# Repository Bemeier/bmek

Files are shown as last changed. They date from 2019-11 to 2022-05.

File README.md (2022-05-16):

# Hardware for BMEK - Bemeier Ergonomic Keyboard

First Alu Prototype

BMEK is an ergonomic keyboard in the spirit of [Lyn's EM7](https://geekhack.org/index.php?topic=83328.0) and [TGR Alice](https://geekhack.org/index.php?topic=95009.0).
Notable differences are the [HHKB-like](https://www.hhkeyboard.com/) layout and the and the more symmetric looks due to the space bars and left key cluster arrangement.

- [Geekhack Thread](https://geekhack.org/index.php?topic=103032.0)
- [Discord Server](https://discord.gg/BFZNmtM)
- [More Pictures 1](https://imgur.com/a/tHlaMWA)
- [More Pictures 2](https://imgur.com/a/MdbbHqe)

## Layout

The main key layout (besides the extra 4 key-cluster on the left) is almost exactly the [Layout of the HHKB](https://deskthority.net/wiki/HHKB_Professional2). The only changes are in the bottom row:

- The 1.5u modifiers are replaced by 1.25u modifiers
- The single spacebar is replaced by two smaller ones

### Layout with PCB V2 + V2.1

These versions of the PCB only support the fixed layout as described above. Note that you'll need 2x2.75 spacebars. Most GMK (spacebar) kits only come with one, but you can always use a 2.75u or 2.25 shift key or spacebar and live with a little gap :)

### Layout with PCB V3

V3 of the PCB supports a 2u backspace option, as well as 2.25u/2.75u layout options for the spacebars (the new version of the case comes with a "blocker" to fill in the gap that is created when using the 2.25u spacebar) and an option to use full or split rshift.

## Firmware

Setup QMK and run `make bemeier/bmek:default`

Alternatively you can download and flash the precompiled firmware from the [Releases](https://github.com/Bemeier/bmek/releases) section. Firmware Source: [TODO: Release](https://github.com/qmk/qmk_firmware/tree/master/keyboards/bemeier/bmek), [Dev](https://github.com/Bemeier/qmk_firmware/tree/bemeier/keyboards/bemeier/bmek)

## PCB

### V3 (latest version)

V3 Image

Version 3 of the PCB comes in either hotswap or solder version. It includes the extra cutouts for the plate screws from v2.1. It further comes with these changes compared to v2.x:

- Layout option backspace: 2u Backspace and 2x 1u hhkb-like
- Layout options bottom row: Each of the 2.75u spacebarss can be replaced with a 2.25u spacebar for better keyset compatibility.
- ESD protection circuity
- Switched to the popular, cheaper and easier to hand-solder HRO-TYPE-C-31-M-12 USB-C receptacle
- Made completely from scratch in KiCad (project will be released as soon as design is verified)

All Gerber & BOM files needed for ordering at JLCPCB are under [pcb](https://github.com/Bemeier/bmek/tree/master/pcb).
It can be ordered with pick-and-place assembly. Only top-mounted LEDs (optional), hot-swap sockets (optional) and USB-C connector need to be ordered separately and soldered by hand.

### Old PCB versions (V2 & V2.1)

With these versions, both hot-swap sockets and permanent soldering are supported. Connector is USB-C, and is confirmed to also work with USB-C to USB-C cables.

PCBv2 top
PCBv2 bottom

### Differences between PCB v2 and v2.1

PCB v2.1 adds some changes to fit the new plate-based design. Namely cutouts to access the scews that mount the plate to the top-case. Note that these are not strictly required to build the new case, but it is a bit more convenient (in case you want to swap out your plate+switch+pcb assembly without desoldering everything).

## Cases

### Top-mounted plate Case (Latest Version)

A top-mounted version of the original case is being designed under [cases/top_mount](https://github.com/Bemeier/bmek/tree/master/cases/top_mount). This is the case I would recommend building - especially if you want to 3D print parts, I'd suggest to print top and bottom case, but get the plate cut/machined from metal (as this is the part where the tolerances are most important.

Top Mounted 1
Top Mounted 2
Top Mounted 3

### Integrated Case (Old Verison)

3D models for a 2-piece high profile case with integrated plate mounts (intended for CNC-machining from polycarbonate or aluminium) are under [cases/old_integrated_plate_case](https://github.com/Bemeier/bmek/tree/master/cases/old_integrated_plate_case).

BMEK
Case Assembled

### Lasercut Case

Lasercut Case material Acrylic. made by [tahutech](https://github.com/TahuTech)

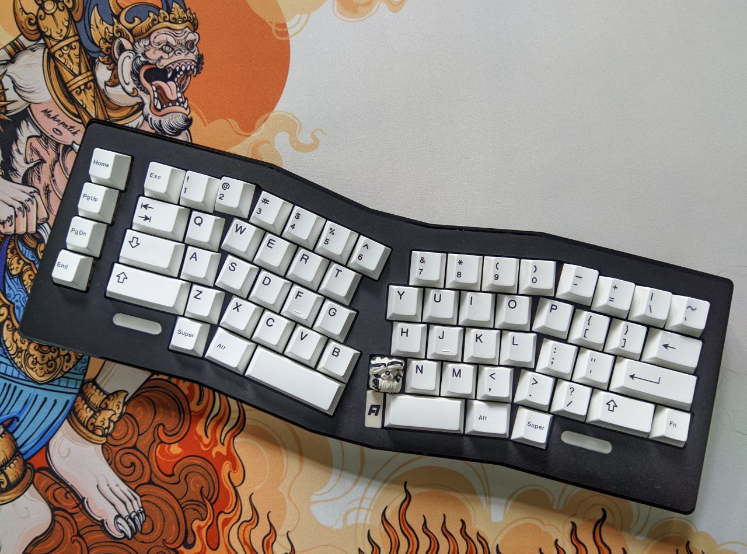
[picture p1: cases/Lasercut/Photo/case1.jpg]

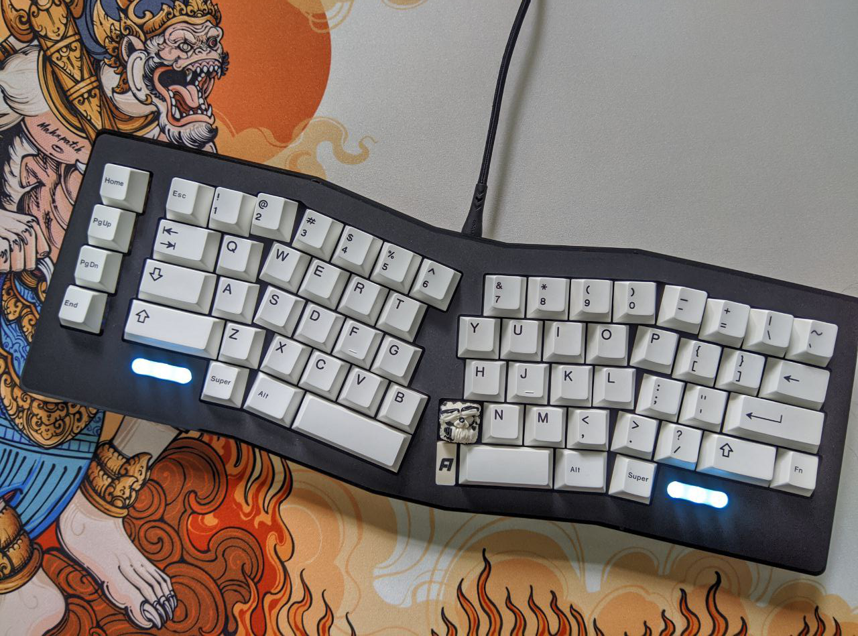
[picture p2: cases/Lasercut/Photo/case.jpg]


## Disclaimer & Contributing

Obviously you will be building the PCB or case at your own risk, but feel free to reach out if you need help or want to contribute. Check out the [geekhack thread](https://geekhack.org/index.php?topic=103032.0), [Discord Server](https://discord.gg/BFZNmtM), or use the issue system on this repository.

## License

<br /><span xmlns:dct="http://purl.org/dc/terms/" property="dct:title">BMEK Mechanical Keyboard</span> by <a xmlns:cc="http://creativecommons.org/ns#" href="http://github.com/Bemeier/bmek" property="cc:attributionName" rel="cc:attributionURL">Jan Kolkmeier</a> is licensed under a <a rel="license" href="http://creativecommons.org/licenses/by/4.0/">Creative Commons Attribution 4.0 International License</a>.

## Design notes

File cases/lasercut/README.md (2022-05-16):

# BMEK Lasercut Case

The Final result after all assemble

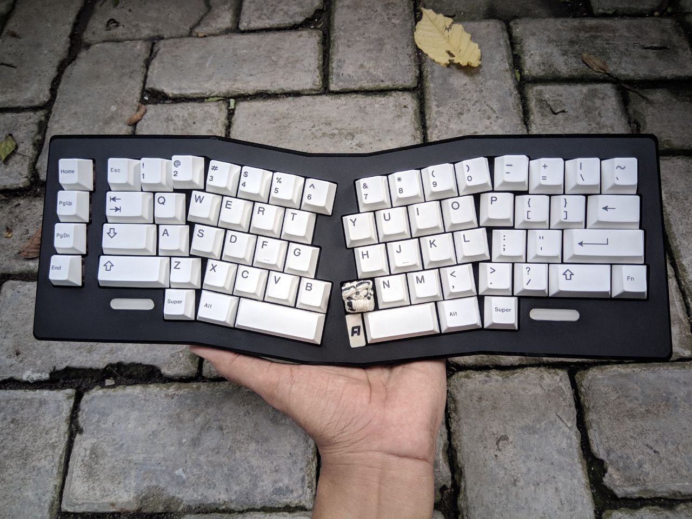
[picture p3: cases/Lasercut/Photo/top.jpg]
Top Case

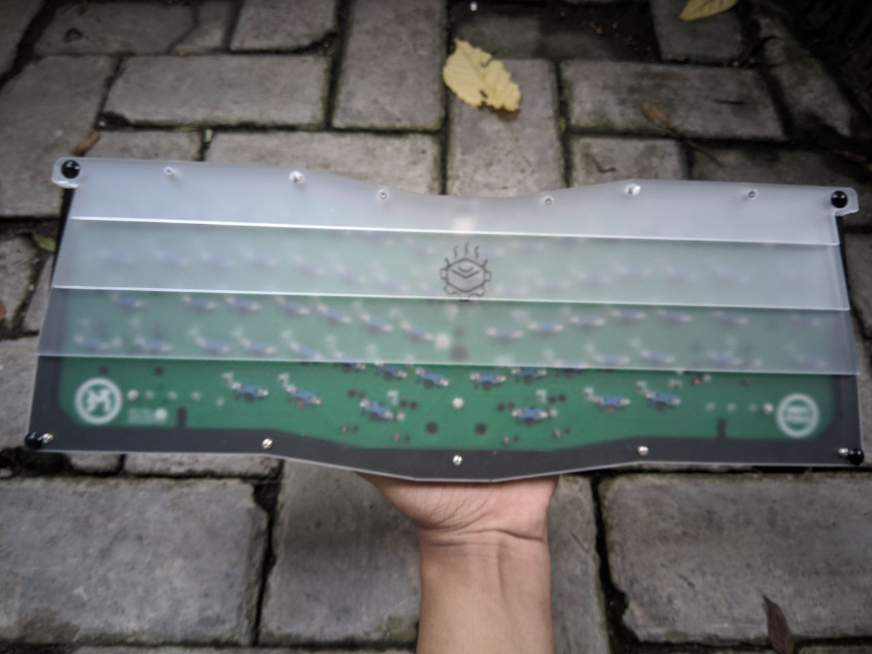
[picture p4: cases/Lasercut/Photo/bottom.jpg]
Bottom Case

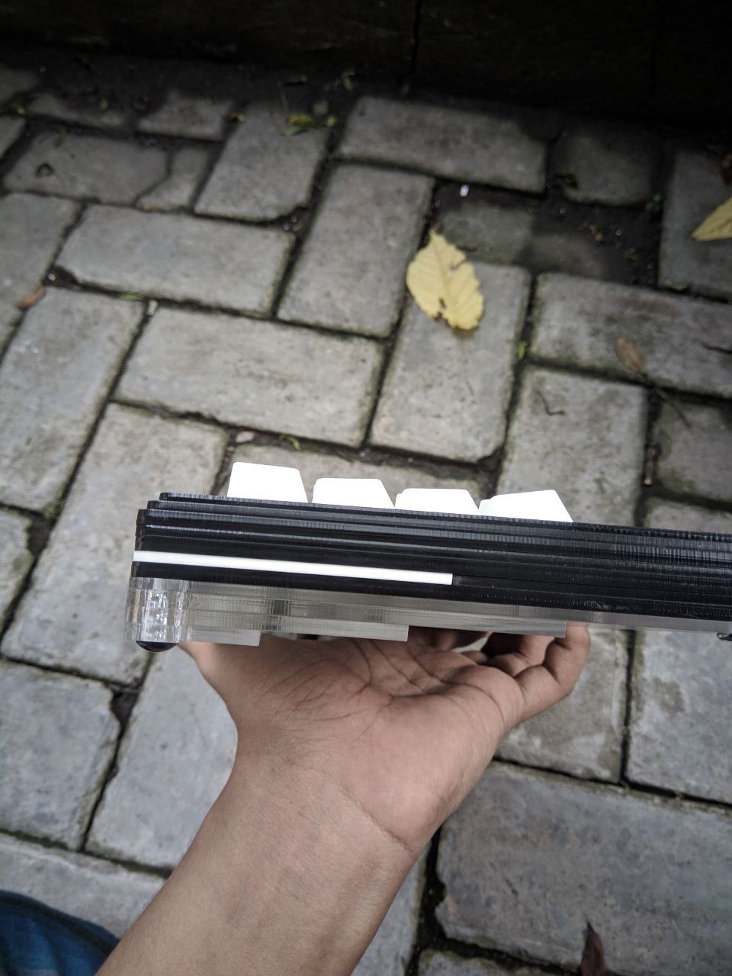
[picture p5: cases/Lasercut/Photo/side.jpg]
Side Case

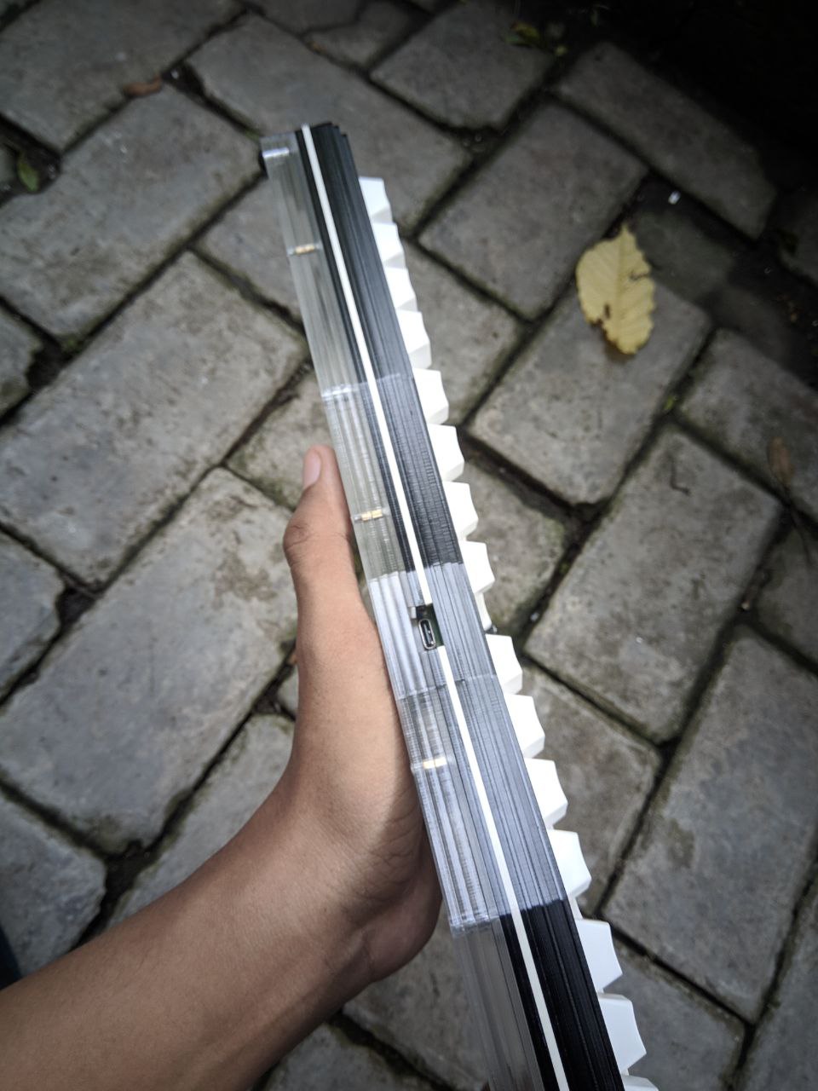
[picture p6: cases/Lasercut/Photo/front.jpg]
Front Case


[Lasercut Album](https://imgbox.com/g/qNx6dZnEyE)

# Spacer And Screws Required:

Feet to Bottom Layer:

- 4x 5mm M2 spacer and 8 screw 5mm M2 to feet (recommend countersunk head).

Top Case (Screwless):

- 9x 5mm M2 screw with countersunk head (install on second layer).
- first layer is glued to the second layer.

Body Case :

- 9x 10mm M2 spacer and 9x 6mm M2 Screw.

Tips on Accent and Blocker:

- just paste it using double tape on bottom side.

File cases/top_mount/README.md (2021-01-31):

# BMEK High-Profile Case with Plate

In each part folder there is a technical drawing, which include annotations of the screw threads.

# Build Instructions

Find some tips and build instructions in Instructions.pdf

# Screws Required:

Bottom Case to Top Case Screws:
- 5x ISO 4762 M2.5x0.45x8mm (Hex head with diameter <=4.5mm) (2.5x0.45x8mm length should also work)

Plate to Top Case Screws:
- 8x ISO 4762 M2x0.4x4mm (Hex head with diameter <= 3.8mm, head hight <= 2mm)

PCB to Top Case Screw:
- 5x ISO 4762 M2x0.4x4mm (Hex head with diameter <= 3.8mm, head hight <= 2mm)

Screw for the 2.25u layout blocker:
- 1x ISO 4762 M2x0.4x4mm

Weight to Bottom Case Screw:
- 3x ISO 10642 M3x0.5x6mm (Sinkhead, total length is <= 6mm) 

# PCB:

Compatible both with the [v3](https://github.com/Bemeier/bmek/tree/master/pcb/v3), [v2](https://github.com/Bemeier/bmek/tree/master/pcb/v2) and [v2.1](https://github.com/Bemeier/bmek/tree/master/pcb/v2_1) of the PCB (however v3/2.1 is recommended, [see this post](https://geekhack.org/index.php?topic=103032.msg2909167#msg2909167))

# Renders

Render

Technical Drawing

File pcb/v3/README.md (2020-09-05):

# V3 of the PCB

This is the PCB as it will be shipped in the group buy. It comes in both a solder and hotswap version. 
I've ordered a test batch from JLCPCB with these files and I'll update the readme here to confirm that it works as expected.
Either way, *order these files at your own risk*.
And most importantly, always critically review the parts placement (oftentimes the previewer on the JLCPCB website is broken, so ask for a review of the parts placement per mail!)

## Improvements over V2/2.1

- Separate design for hotswap and solder versions (to avoid the [potential interference issue](https://www.youtube.com/watch?v=Bh93sXRh4x4&vl=en) with the previously south facing  option when using hotswap sockets)
- Layout options:
  - backspace: 2u Backspace and 2x 1u hhkb-like
  - bottom row: The 2.75u spacebar can be replaced with a 2.25u spacebar for better keyset compatibility.
  - Split left shift option (ISO style)
  - 2.75u right shift option (besides the default split right shift)
- ESD protection circuity
- Switched to the popular, cheaper and easier to hand-solder [HRO-TYPE-C-31-M-12](https://lcsc.com/product-detail/USB-Type-C_Korean-Hroparts-Elec-TYPE-C-31-M-12_C165948.html) USB-C receptacle

## Kicad Project
For this version, I've also released the Kicad projects (see ../kicad/projects).

## Hotswap Version
Hotswap Version Image

## Solder Version
Solder Version Image

## Crosshatch Back:
There are two versions exported, one with the crosshatched pattern on the back (shown below) and one without (shown above).
The crosshatch pattern increases the gerber filesize significantly, which made the JLCPCB gerber viewer choke completely to the point that I couldn't go through the order process properly.

Crosshatch Back Image

## Ordering on JLCPCB
These are the basic steps for ordering V3 PCBs from JLCPCB. Please note a couple important things: 
- If you do not pay/have them install the SMD components, you will have to order those and install them manually
- Regardless of choosing to have them install SMD components, they do not support installing the USB C port (required), LEDs (optional), or hotswap sockets (required for building hotswap PCB). These will need to be acquired and installed manually.
- Grab the latest version of the necessary files (pretty much everything in `pcb/v3` folder)
- This is DIY. You will have to solder _at least_ the USB C port. You will also have to source this (and other optional parts) yourself.
- Read through, and understand, these steps AND everything detailed on this page before continuing. Make sure you understand **and** accept all risks you are taking. This guide is to help those with questions who have never used JLPCB before. It's relevancy may change as files change OR jlcpcb's services or site change.

1. Go to [JLCPCB](http://www.jlcpcb.com).
2. Find the '2  Layers' graphic and click 'Quote Now'.
3. On the new page, click the 'Add your gerber file' button.
4. Find an select your desired file within `pcb/v3` folder (don't unzip). It will take a while to upload the file. Go grab a snack and give it some time. Good things come to those who wait.
5. After the file has finished uploading (it'll say completed and the loading bar gone), you'll likely have to manually enter the Dimensions: 115mm x 354mm. Everything else should be entered correctly.
6. If you **DO NOT** want to have jlcpcb do SMT assembly, SKIP TO STEP 10. 
7. For SMT Assembly, you'll want to select the toggle towards the bottom (SMT Assembly). If you see an error, it's likely because you skipped the step about entering dimensions above. If that wasn't it, review the error and address it. Also select the following options:
   1. 'Assemble bottom side' - needs to be selected
   2. 'SMY QTY' - set to your desired quantity
   3. 'Tooling holes' - select 'Added by JLCPCB'
   4. Once all is set, click 'Confirm' button (not the 'Next' button) It will redirect you to create an account or sign in - once done, you should be redirect back to the order page. You'll need to click 'Confirm' again.
8. You should now be on a page for uploading a 'BOM' and 'CPL' file. These files are also in the `pcb/v3` folder. Upload the correct file to it's correlating upload button. ('Add BOM File' and 'Add CPL File') and click 'Next'. Files:
   1. V3_BOM_JLC
   2. V3_CPL_JLC
9.  It should auto-find all necessary parts. You will see one item `HRO-TYPE-C-31-M-12` that says 'No part selected'. This is the USB C port which has to be acquired and installed manually. Click 'Next'.
10. If everything looks good (make sure you entered dimensions from step 5), you should be ready to 'SAVE TO CART' and continue to check out. If you didn't create an account earlier, you're going to be asked to do so before being able to checkout. 
11. Don't forget to source the USB C port you will need. You're going to need enough to cover all the PCBs you're ordering (or as many as you want to build). `HRO-TYPE-C-31-M-12` should be easily found online from multiple vendors.

### Checking DFM
Since the preview for the parts placement often fails on the JLCPCB website, it is good to check it after the JLC engineers have processed it.
To do this, click on the "DFM Analysis" on the order page, it will show something like this:

DFM Analysis Screenshot

Make sure that the orientation of the parts (as denoted by the red dots and the +/-) looks like this (both for hotswap and solder, click the image for a high resolution image):

Correct component placement (https://i.imgur.com/kTeKakS.png)

Again, the DFM Analysis will only be made available after the engineers have processed it (can take up to 24h). The actual pick and place process only starts after the PCB is manufacuterd, so you have some time to check this for errors. I usually just send them a mail to hold on the Pick'n'Place until I got a chance to verify the DFM.

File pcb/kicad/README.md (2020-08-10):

# Kicad Project

There are two projects, one for the solder version, one for the hotswap version.

You'll need a recent nightly version of Kicad to open these (sorry, next time I'll use stable to create a project :) ).

This project contains V3 of the PCBs (see ../v3)

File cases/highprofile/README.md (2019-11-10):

# BMEK High-profile Case

First Prototype made with an Isel ICP 4030:

Case Assembled

[Imgur Album](https://imgur.com/a/tHlaMWA)

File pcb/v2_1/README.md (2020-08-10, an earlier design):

# BMEK PCB v2.1

**Use at your own risk.**

- Contains some updates for the [separate plate case](https://github.com/Bemeier/bmek/blob/master/cases/highprofile_plate/)
- The PCB has been made and works. But it hasn't been tested with assembly yet, so please be double-critical when reviewing the Pick & Place positioning & components, in case you want to order this one assembled
- You most likely want to make v3 instead, it has several improved features such as ESD protection, multiple layout options and a nicer logo.
- Reasons to still be using this old version is that it combines hotswap and solder in a single design, and that it uses a more sturdy (but also more expensive) usb-c connector.

[Web preview](https://a360.co/2XrYdaG)

PCB Preview

## BOM

See [BOM for v2](https://github.com/Bemeier/bmek/tree/master/pcb/v2/jlcpcb#bom-v2--v21)

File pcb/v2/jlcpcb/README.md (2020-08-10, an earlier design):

# Ordering v2 at JLCPCB

- **Use at your own risk.**
- This is outdated and doesn't fit the new case well due to the missing access cutouts for the plate screws. Consider making V3 instead!
- But if you must, go to [jlcpcb.com](https://jlcpcb.com) and get a quotation. Use the .zip for uploading gerber files. For assembly, use BOM_LED.csv and CPL_LED.csv.

PCB
PCBv2 top
PCBv2 bottom

### BOM V2 & V2.1

**Part Detail**|**Unit Price**|**Quantity**
-----|-----|-----
Tactile Switches SPST 5.10mm x 5.10mm 0.40mm 50mA @ 12VDC SMD C318884|€0.07|1
ATMEL & AVR QFP-44\_10x10x08P C44854|€3.26|1
Multilayer Ceramic Capacitors MLCC - SMD/SMT 22pF 50V 0603 C1653|€0.01|2
Chip Resistor - Surface Mount 10KOhms ±1% 1/10W 0603 C25804|€0.00|2
Chip Resistor - Surface Mount 470Ohms ±1% 1/10W 0603 C23179|€0.02|1
Multilayer Ceramic Capacitors MLCC - SMD/SMT 100nF 50V 0603 C14663|€0.00|12
Multilayer Ceramic Capacitors MLCC - SMD/SMT 1uF 50V 0603 C15849|€0.04|1
Schottky Barrier Diodes (SBD) SOD-123 C8598|€0.14|1
Multilayer Ceramic Capacitors MLCC - SMD/SMT 4.7uF 16V 0603 C19666|€0.06|1
Switching Diode 75V 150mA 1.25V @ 150mA 4ns SOD-123 C81598|€0.01|66
Chip Resistor - Surface Mount 22Ohms ±1% 1/10W 0603 C23345|€0.01|2
SMD Crystal Resonators 16MHz ±10ppm SMD-3225\_4P C13738|€0.38|1
Chip Resistor - Surface Mount 5.1KOhms ±1% 1/10W 0603 C23186|€0.00|2
Light Emitting Diodes (LED) -WS2812B-B C114586|€0.10|6
USB-C Receptacle - 632723300011|€4.00|1

## Changelog

### PCBv2.zip (tested and works!)
- Improve decoupling capacitor positioning
- Moved atmega closer to USB port
- Added hot-swap sockets
- Top layer footprints for 6x optional WS2812b 

### PCBv1.zip
- First version

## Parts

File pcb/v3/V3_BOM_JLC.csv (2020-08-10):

Comment | Designator | Footprint | LCSC Part #
22pF | C1,C2 | C_0603_1608Metric | C1653
1uF | C3 | C_0603_1608Metric | C15849
0u1F | C4,C5,C6,C7,C8,C9,C12,C13,C14,C15,C16,C17 | C_0603_1608Metric | C14663
4u7F | C10 | C_0603_1608Metric | C19666
4n7F | C11 | C_0603_1608Metric | C159797
SMF6.0A | D1 | D_SOD-123 | C123790
WS2812B | D2,D3,D4,D5,D6,D7 | LED_WS2812B_PLCC4_5.0x5.0mm_P3.2mm | C114586
1N4148W | DU_0_0,DU_0_1,DU_0_2,DU_0_3,DU_0_4,DU_0_5,DU_0_6,DU_0_7,DU_0_8,DU_0_9,DU_0_10,DU_0_11,DU_0_12,DU_0_13,DU_0_14 | D_SOD-123 | C81598
1N4148W | DU_1_0,DU_1_1,DU_1_2,DU_1_3,DU_1_4,DU_1_5,DU_1_6,DU_1_7,DU_1_8,DU_1_9,DU_1_10,DU_1_11,DU_1_12,DU_1_13,DU_1_14 | D_SOD-123 | C81598
1N4148W | DU_2_0,DU_2_1,DU_2_2,DU_2_3,DU_2_4,DU_2_5,DU_2_6,DU_2_7,DU_2_8,DU_2_9,DU_2_10,DU_2_11,DU_2_12,DU_2_13,DU_2_14 | D_SOD-123 | C81598
1N4148W | DU_3_0,DU_3_1,DU_3_2,DU_3_3,DU_3_4,DU_3_5,DU_3_6,DU_3_7,DU_3_8,DU_3_9,DU_3_10,DU_3_11,DU_3_12,DU_3_13,DU_3_14 | D_SOD-123 | C81598
1N4148W | DU_4_1,DU_4_2,DU_4_3,DU_4_5,DU_4_8,DU_4_10,DU_4_11 | D_SOD-123 | C81598
TLC-PSMD050 | F1 | Fuse_0805_2012Metric | C261942
22Ω | R1,R2 | R_0603_1608Metric | C23345
5k1Ω | R3,R4 | R_0603_1608Metric | C23186
1MΩ | R5 | R_0603_1608Metric | C22935
10kΩ | R6,R7 | R_0603_1608Metric | C25804
470Ω | R8 | R_0603_1608Metric | C23179
TS-1187A-B-A-B | SW1 | TS-1187A-B-A-B | C318884
ATmega32U4-AU | U1 | TQFP-44_10x10mm_P0.8mm | C44854
USBLC6-2SC6 | U2 | SOT95P280X145-6N | C7519
HRO-TYPE-C-31-M-12 | USB1 | HRO-TYPE-C-31-M-12-HandSoldering | C165948
Crystal_GND24_Small | Y1 | SMD3225 | C13738

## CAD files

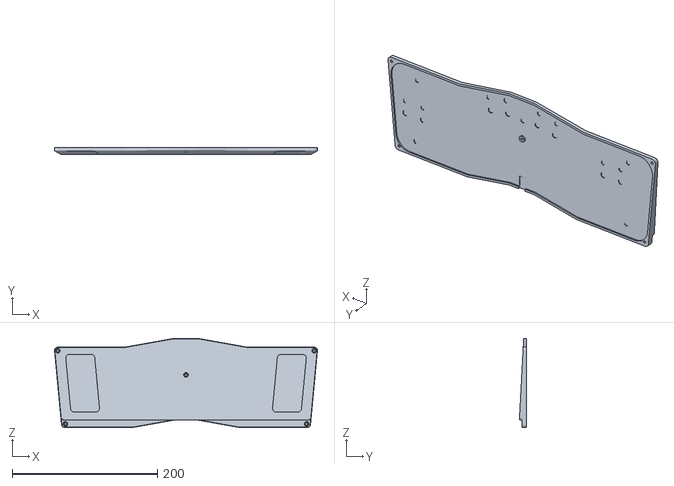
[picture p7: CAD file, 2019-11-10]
cases/highprofile/CaseBottom.stl
362.7 x 10.0 x 122.9

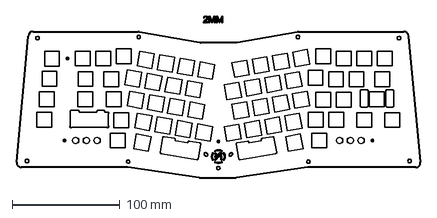
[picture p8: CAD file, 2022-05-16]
cases/Lasercut/plate.dxf
375.6 x 150.5 mm

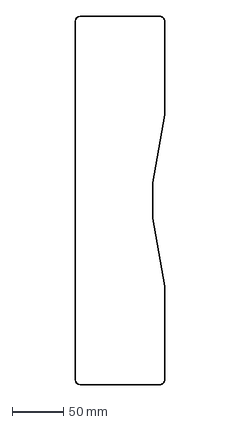
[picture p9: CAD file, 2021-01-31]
cases/Lasercut/WristRest/WristRest.dxf
87.5 x 360.0 mm

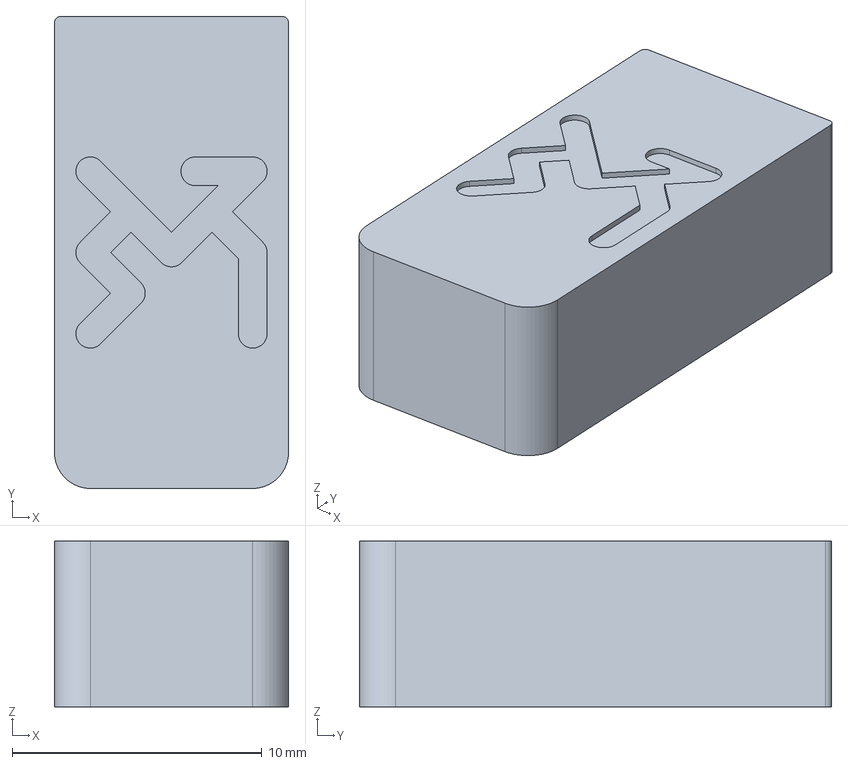
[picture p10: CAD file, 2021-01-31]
cases/top_mount/Blocker/Blocker_EngravedLogo.step
9.38 x 18.9 x 6.65 mm

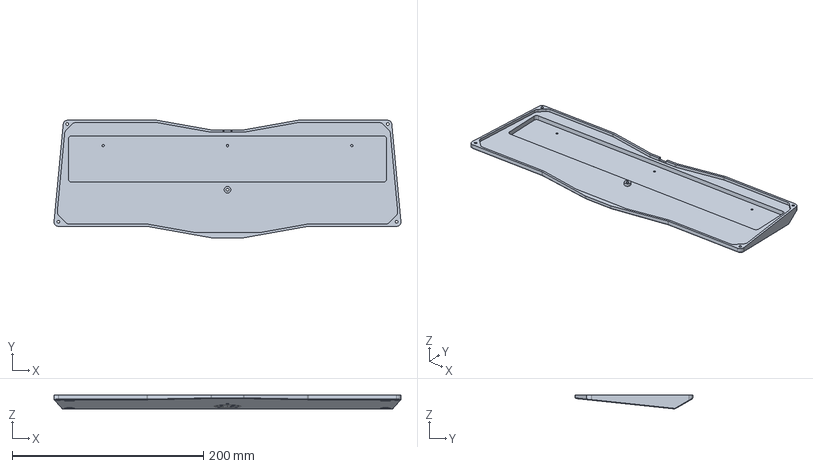
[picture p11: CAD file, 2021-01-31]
cases/top_mount/BottomCase/BottomCase.step
362.7 x 122.9 x 14.5 mm

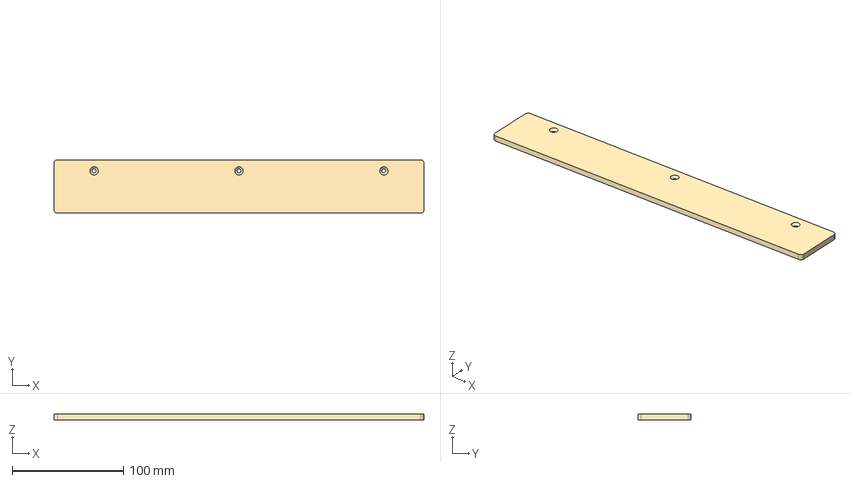
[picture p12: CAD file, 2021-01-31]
cases/top_mount/BottomWeight/BottomWeight.step
332.0 x 48.0 x 5.00 mm

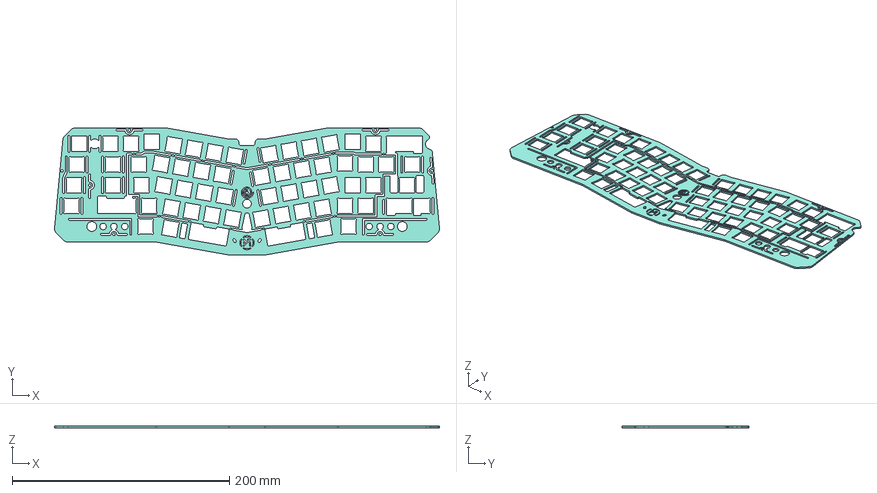
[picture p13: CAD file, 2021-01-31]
cases/top_mount/SwitchPlate/SwitchPlate_ThreeQuarterFlex.step
354.8 x 117.1 x 1.50 mm

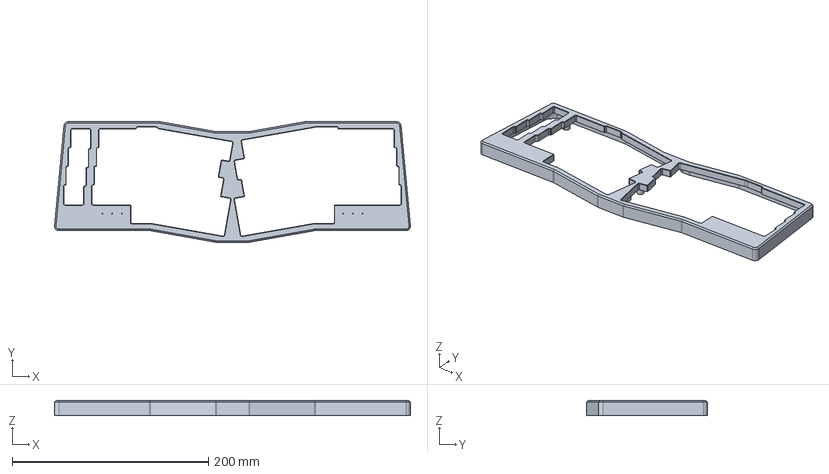
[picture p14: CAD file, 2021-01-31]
cases/top_mount/TopCase/TopCase.step
362.7 x 122.9 x 14.9 mm

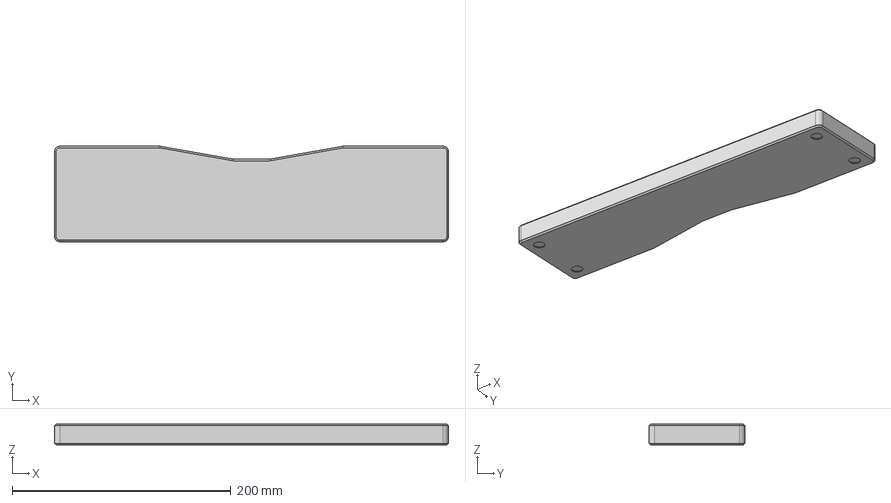
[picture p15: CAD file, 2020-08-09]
cases/top_mount/WristRest/WristRest.step
360.0 x 87.5 x 19.0 mm

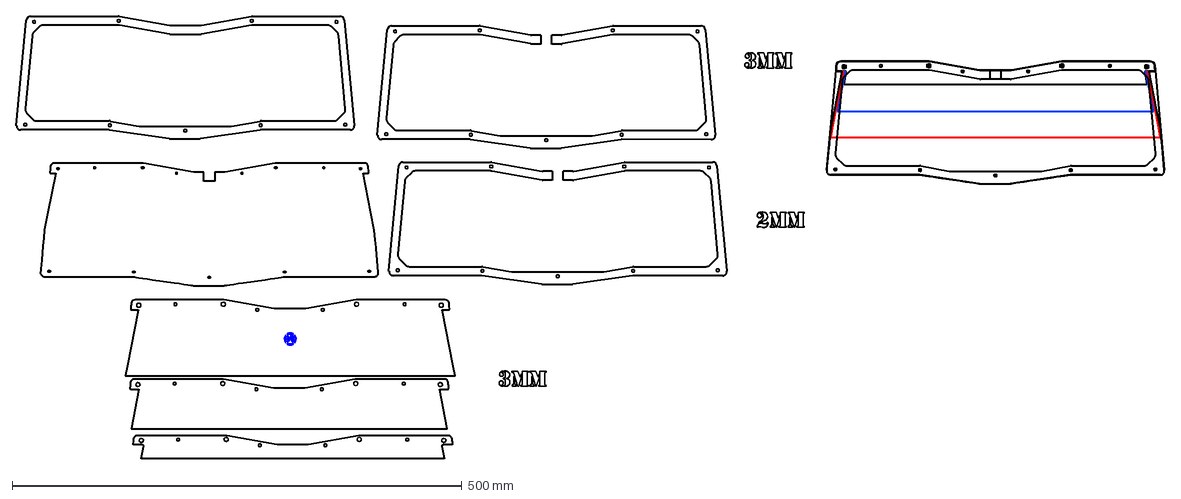
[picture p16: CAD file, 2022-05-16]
cases/Lasercut/bottom and feet.dxf
1275.8 x 491.3 mm

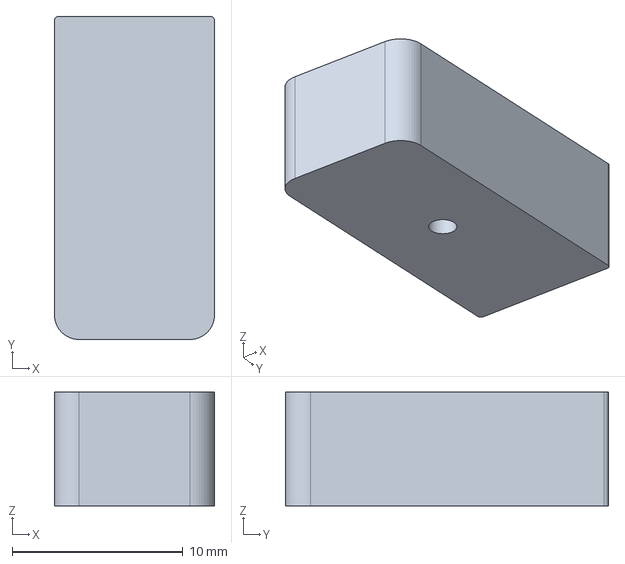
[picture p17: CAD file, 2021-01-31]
cases/top_mount/Blocker/Blocker.step
9.38 x 18.9 x 6.65 mm

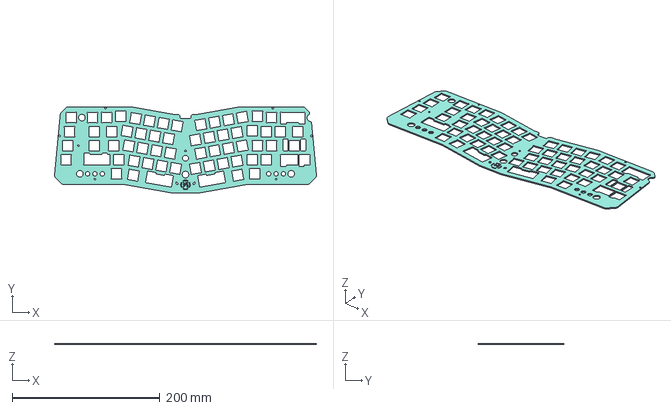
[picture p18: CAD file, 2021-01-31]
cases/top_mount/SwitchPlate/SwitchPlate.step
354.8 x 117.1 x 1.50 mm

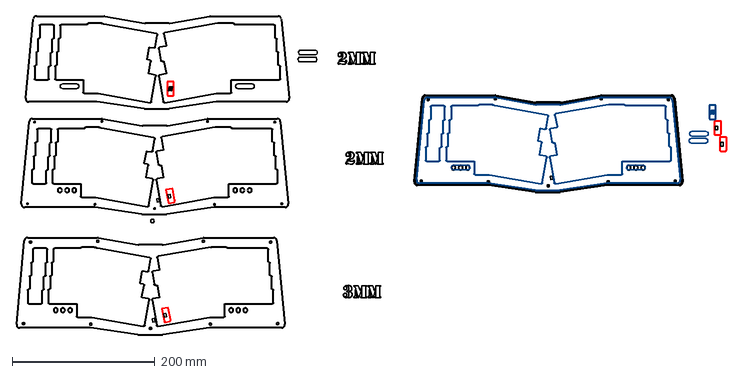
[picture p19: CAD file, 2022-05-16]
cases/Lasercut/top case bmek.dxf
993.6 x 446.2 mm

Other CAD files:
cases/top_mount/Blocker/Blocker.stl
cases/top_mount/BottomCase/BottomCase.stl
cases/top_mount/SwitchPlate/SwitchPlate.dxf
cases/top_mount/SwitchPlate/SwitchPlate_ThreeQuarterFlex.dxf
cases/top_mount/TopCase/TopCase.stl
cases/top_mount/WristRest/WristRest.stl

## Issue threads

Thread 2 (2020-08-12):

Production details

lihaksa, 2020-08-12:
Dear dev,

I tried sending the Gerber file to my local Pcb manufacturer but they asked for the following details (they said these were missing):

Pcb Material                           
Pcb Layer Account
Pcb Board Thickness         
Copper Thickness
Inner Copper Thickness
Soldermask Color
Silkscreen Color
Surface Finish                               
Panelization           
Technical Border (Strip)              
“Multilayer: Stack-up, Impedance Control, Via Filled Type etc.”

So sorry for being such a noob. Any help would be greatly appreciated.

Thanks so much in advance!

jankolkmeier, 2020-08-12:
I highly recommend you to look up some resources explaining what all of these manufacturer terms mean before just blindly ordering something from a manufacturer. The best way to learn is to put in a little effort yourself first. That will also help you deal with other issues you might face down the line!

That being said, It's a simple 2 layer board, 1.5mm thickness, FR4 material likemost keyboard pcbs. Rest is up to you.

jankolkmeier, 2020-08-12:
Actually, let me reopen this b/c I think it's a fair point that I should add this info to the documentation (even if it would be obvious to most,I did notice there are a couple of people that picked this as their first project)

lihaksa, 2020-08-13:
Thank you so much.

Bobthebearfood, 2022-02-25:
May be a stupid question because this is my first real custom, but when I search HRO-TYPE-C-31-M-12 on google, the result is an smd port, but in the picture, the port looks through hole. Which is it?

jankolkmeier, 2022-02-26:
You're right, the pictures on the main page are from the prototype PCB (v2) and are using Wuerth part-through hole, part smd usb receptacles. The latest versions (v2.1 and v3) use the smd-only connector of the type that you're referring to (HRO-TYPE-C-31-M-12 )

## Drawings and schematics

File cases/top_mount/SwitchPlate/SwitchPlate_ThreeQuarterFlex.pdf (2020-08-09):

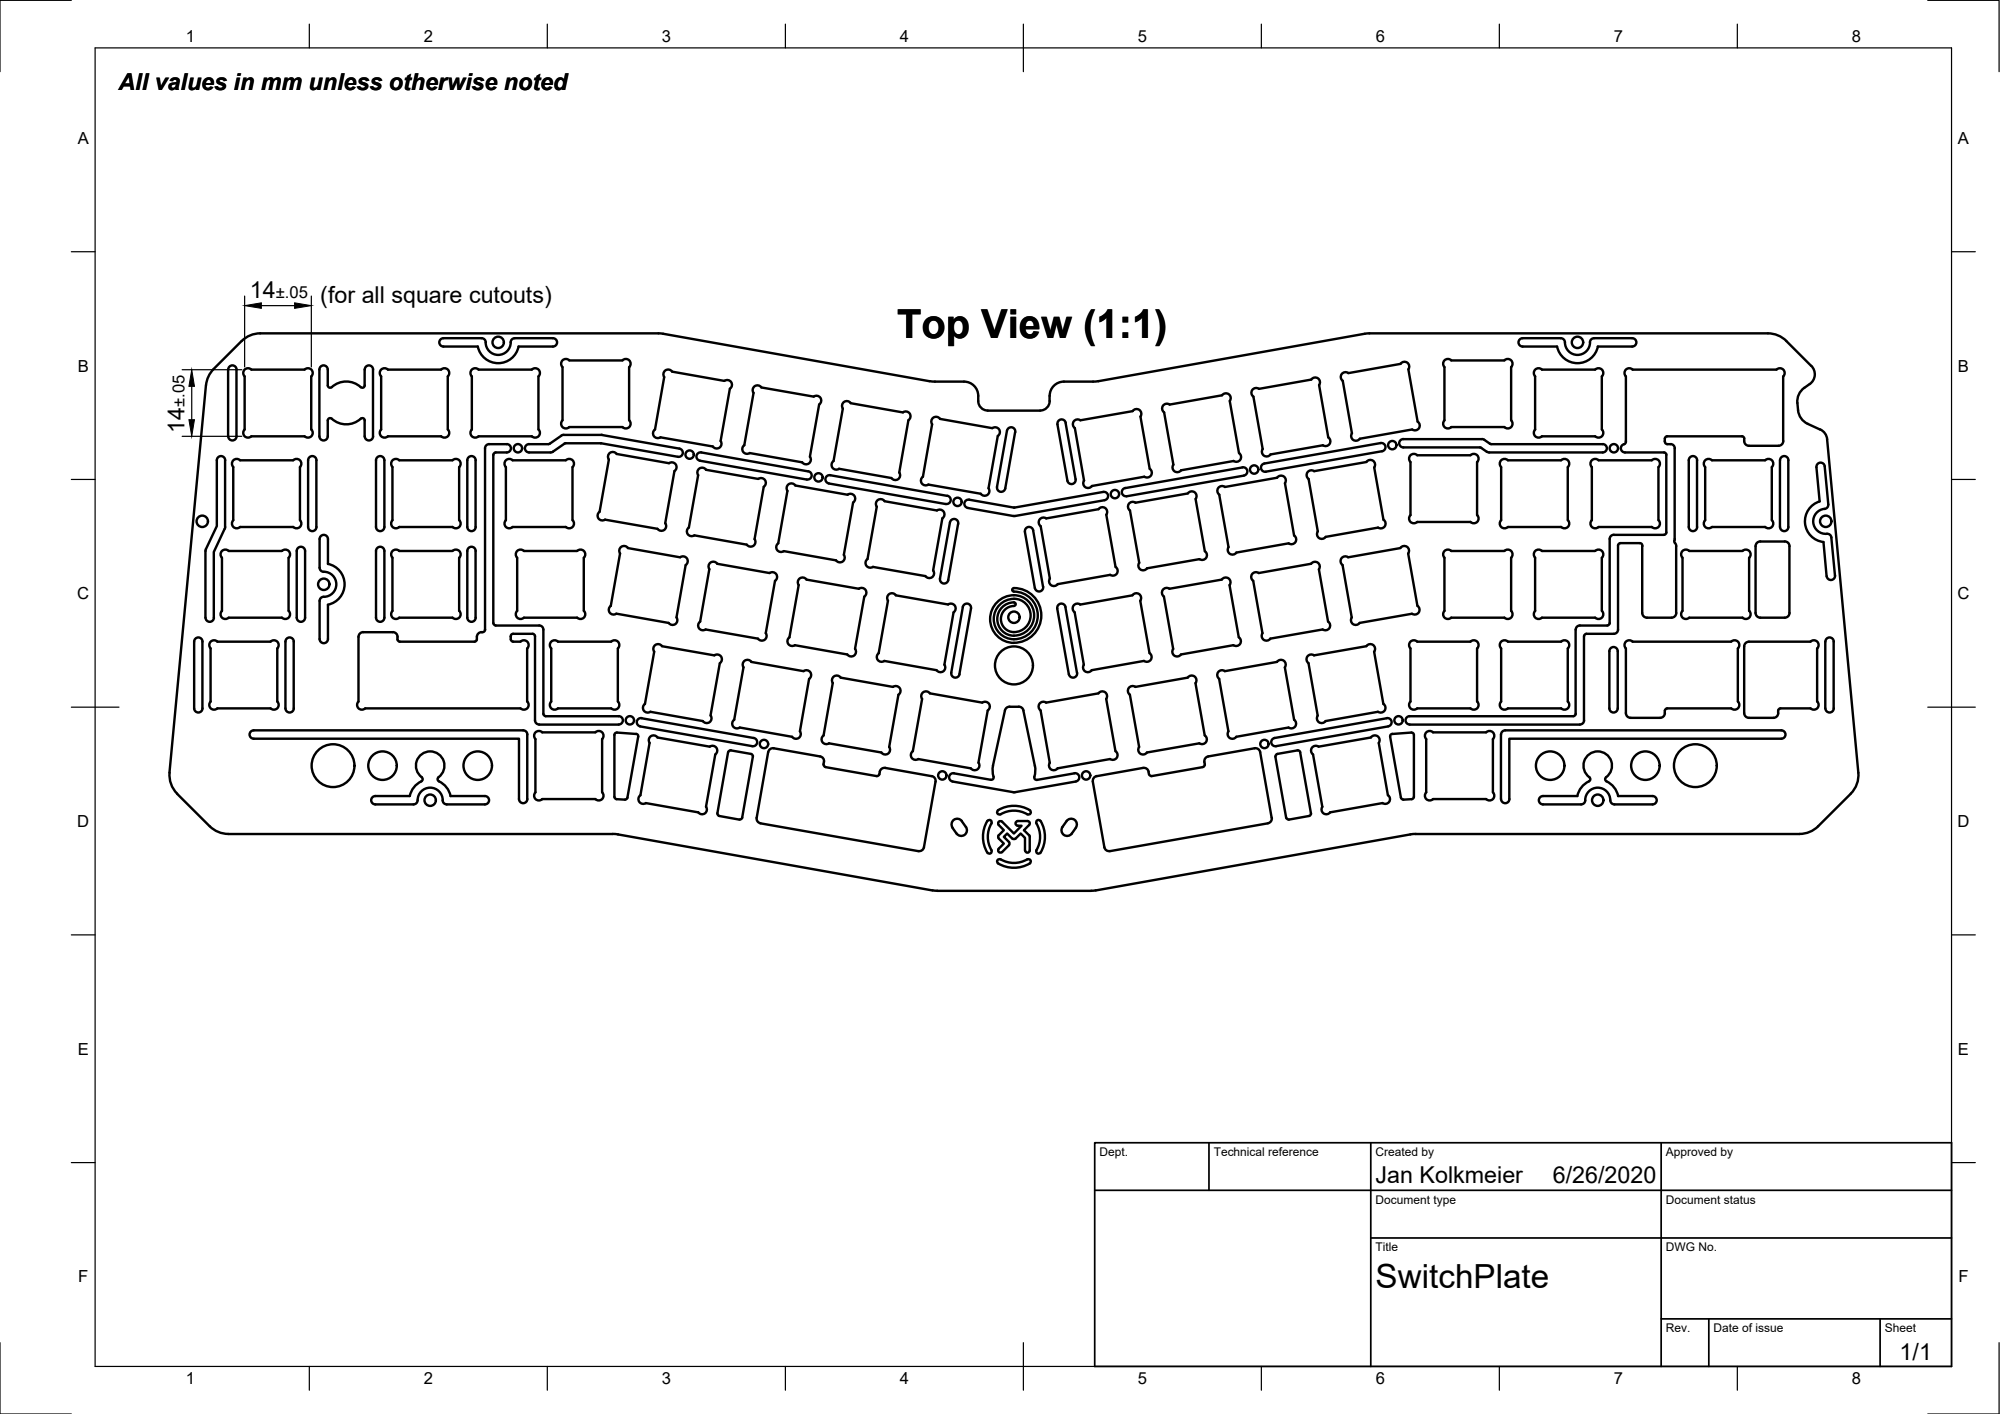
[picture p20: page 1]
Top View (1:1); (for all square cutouts) 14±.05

All values in mm unless otherwise noted

Dept. | Technical reference | Created by Jan Kolkmeier 6/26/2020 | Approved by

Document type | Document status

Title SwitchPlate | DWG No.

Rev. | Date of issue | Sheet 1/1

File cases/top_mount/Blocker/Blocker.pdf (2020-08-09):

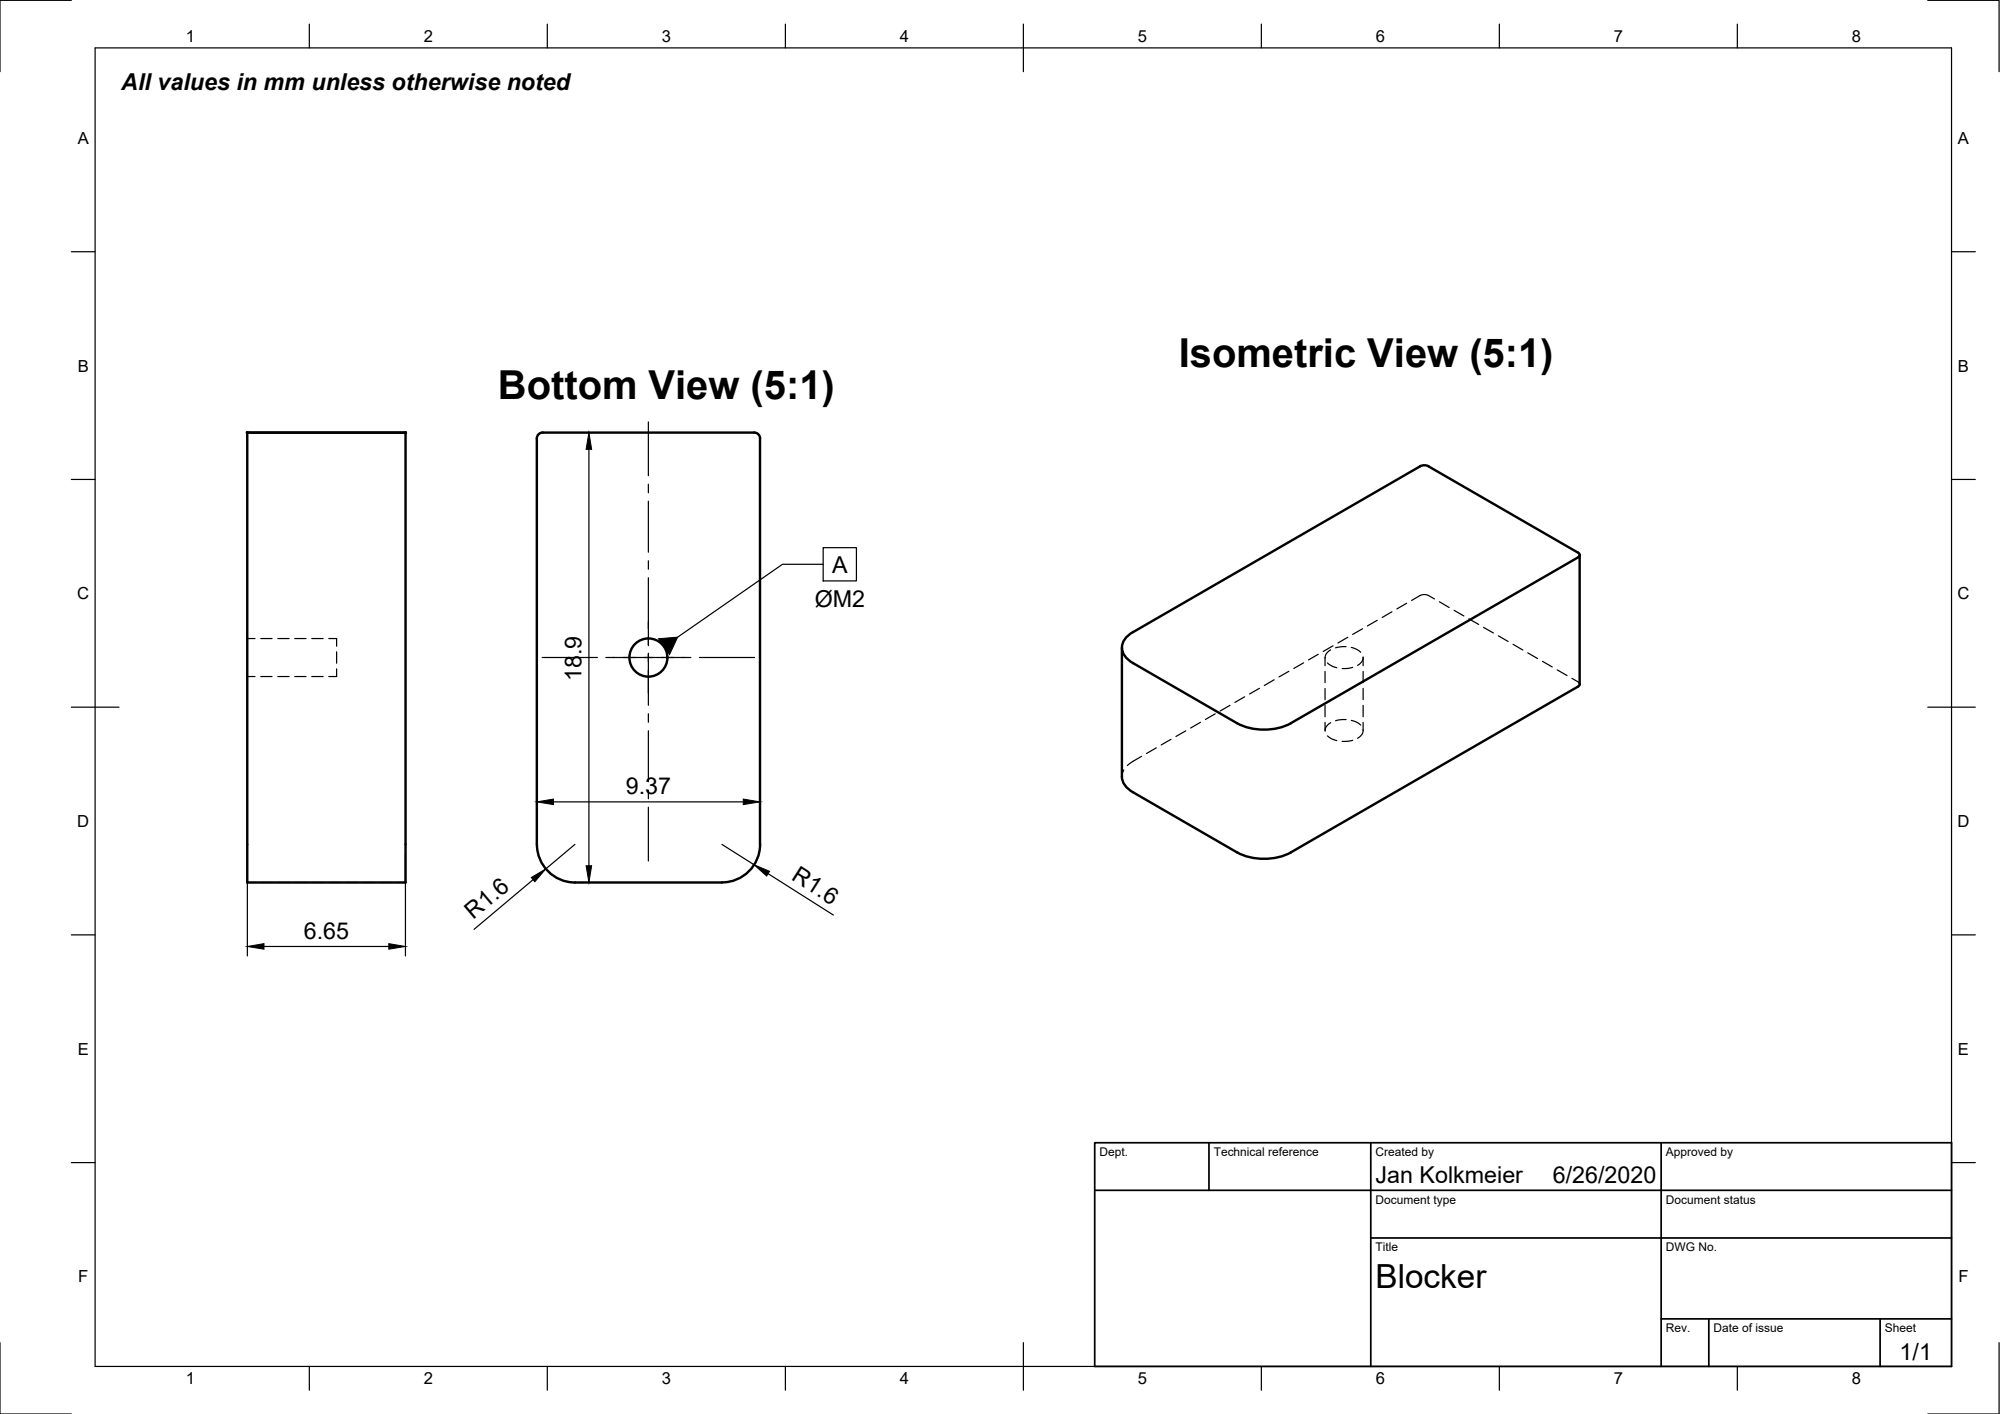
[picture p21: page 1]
Bottom View (5:1); Isometric View (5:1)

All values in mm unless otherwise noted

Dept. | Technical reference | Created by Jan Kolkmeier 6/26/2020 | Approved by

Document type | Document status

Title Blocker | DWG No.

Rev. | Date of issue | Sheet 1/1

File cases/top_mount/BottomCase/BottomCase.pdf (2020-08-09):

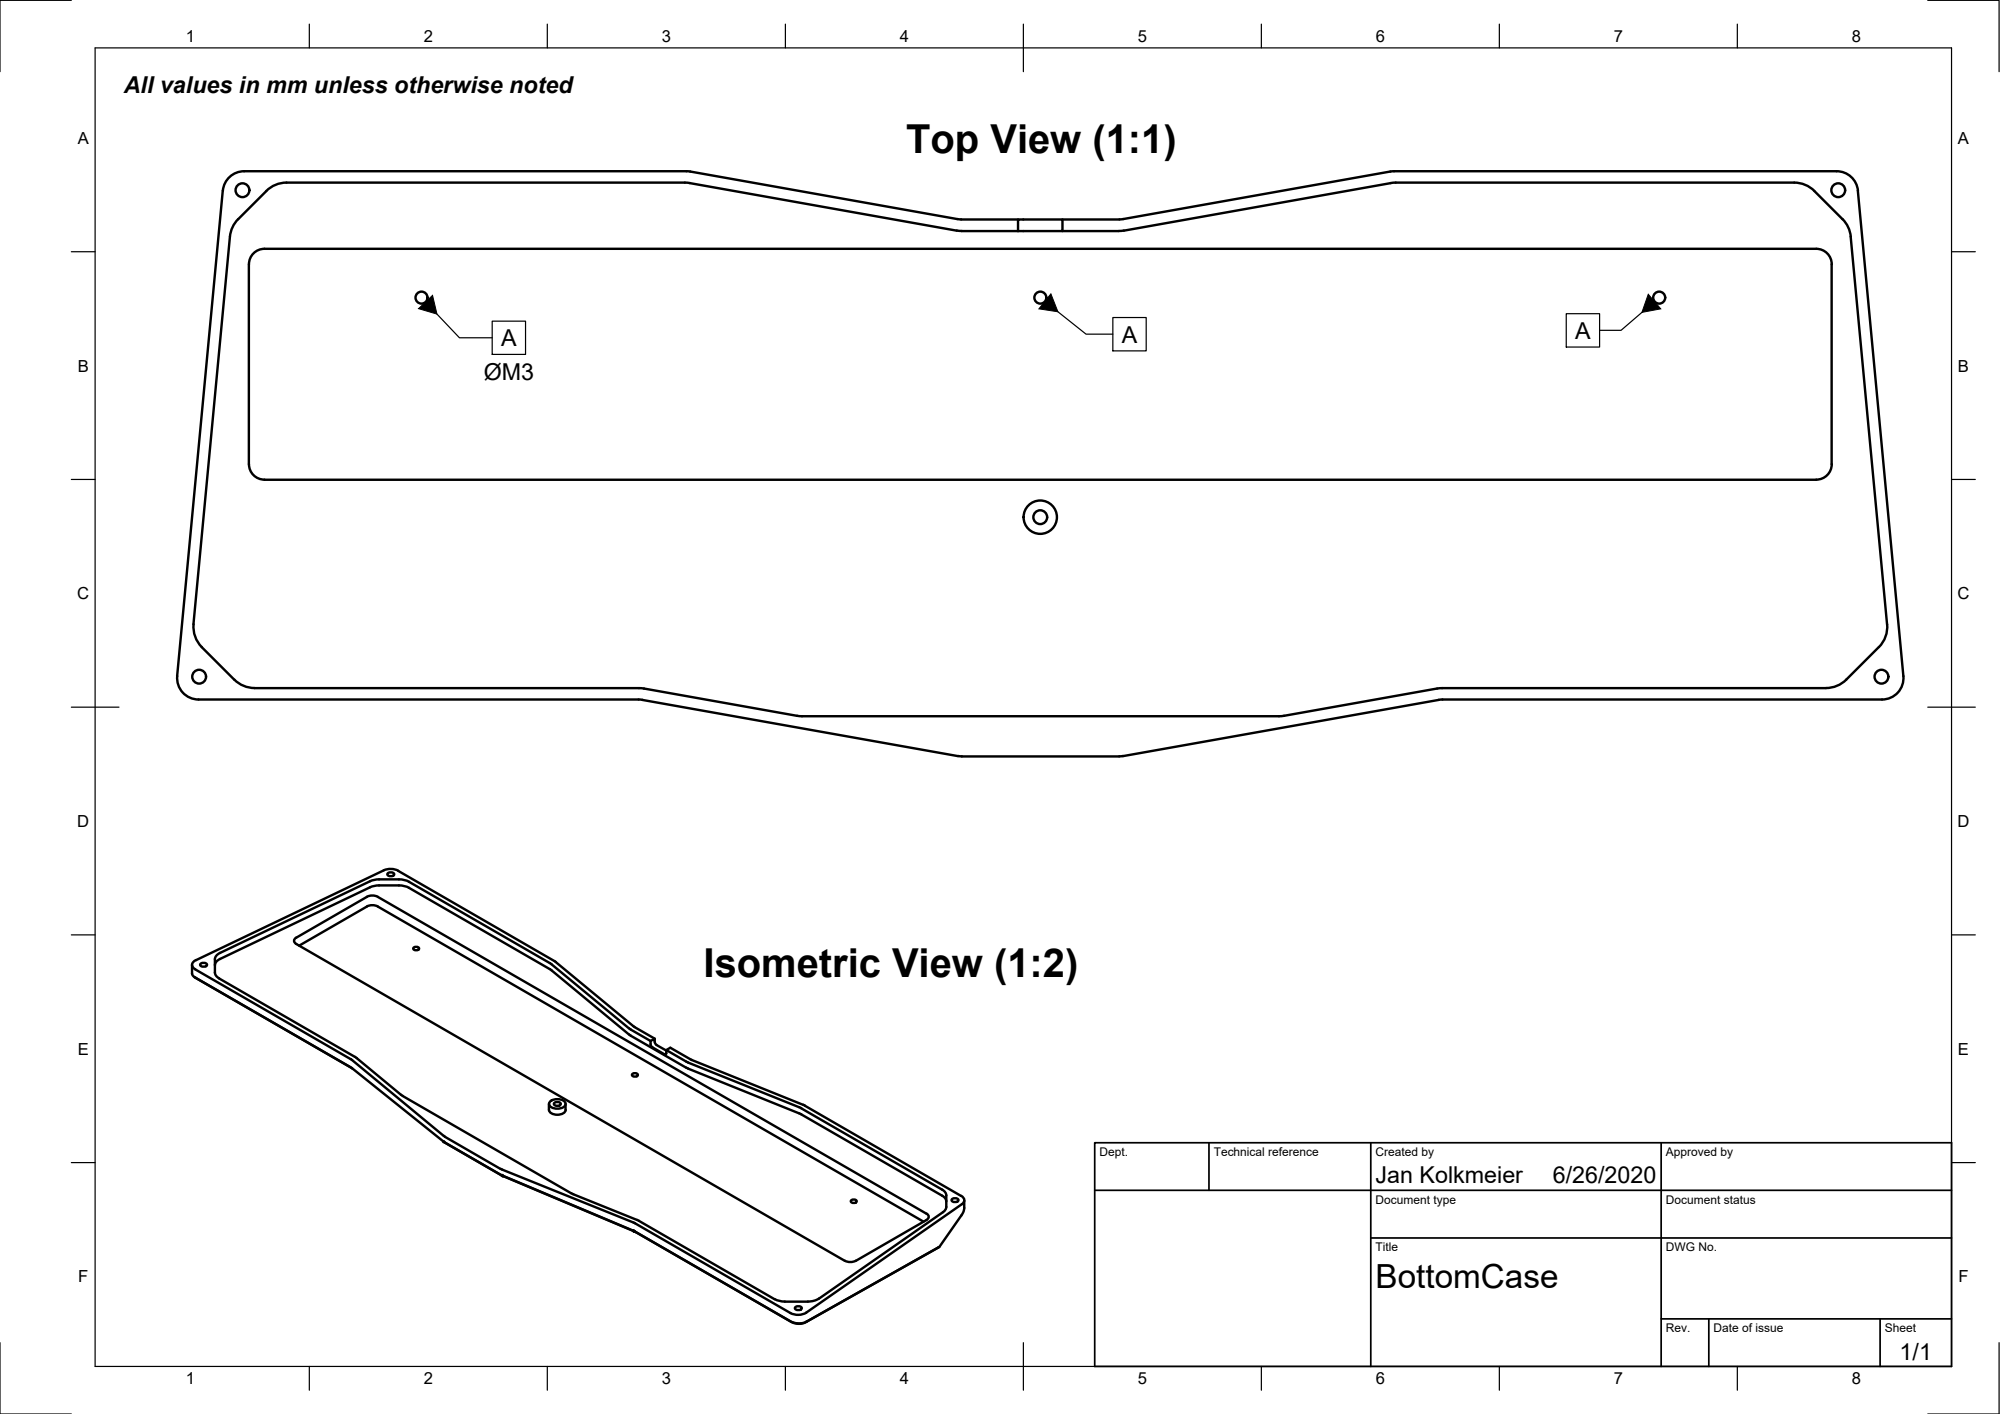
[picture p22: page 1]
Top View (1:1); Isometric View (1:2)

All values in mm unless otherwise noted

Dept. | Technical reference | Created by Jan Kolkmeier 6/26/2020 | Approved by

Document type | Document status

Title BottomCase | DWG No.

Rev. | Date of issue | Sheet 1/1

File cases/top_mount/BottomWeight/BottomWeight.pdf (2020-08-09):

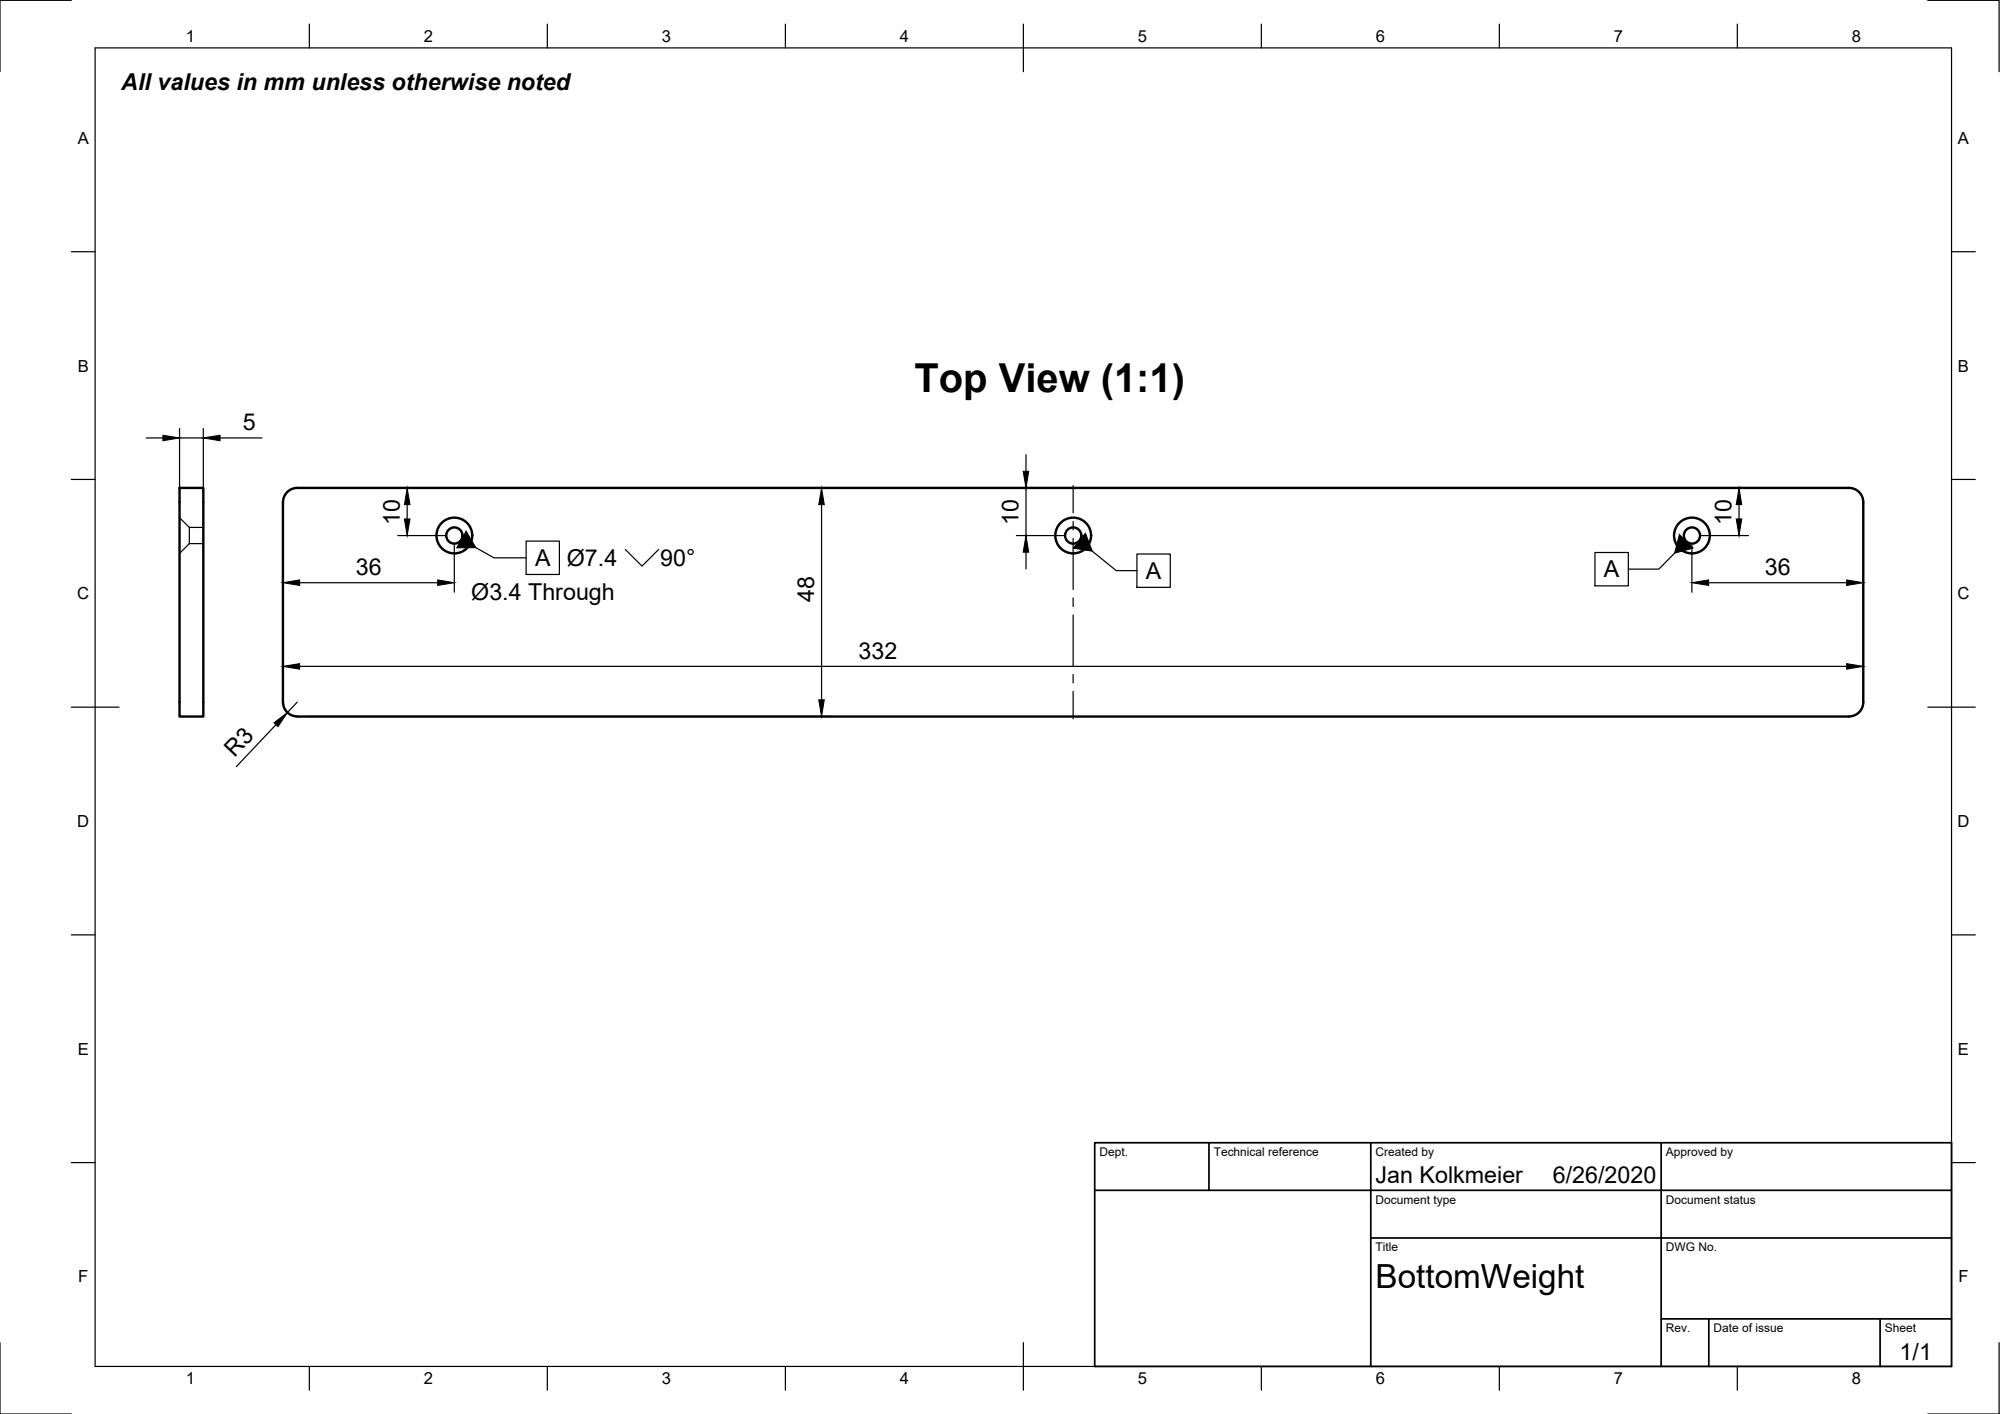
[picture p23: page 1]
Top View (1:1); Ø3.4 Through

All values in mm unless otherwise noted

Dept. | Technical reference | Created by Jan Kolkmeier 6/26/2020 | Approved by

Document type | Document status

Title BottomWeight | DWG No.

Rev. | Date of issue | Sheet 1/1

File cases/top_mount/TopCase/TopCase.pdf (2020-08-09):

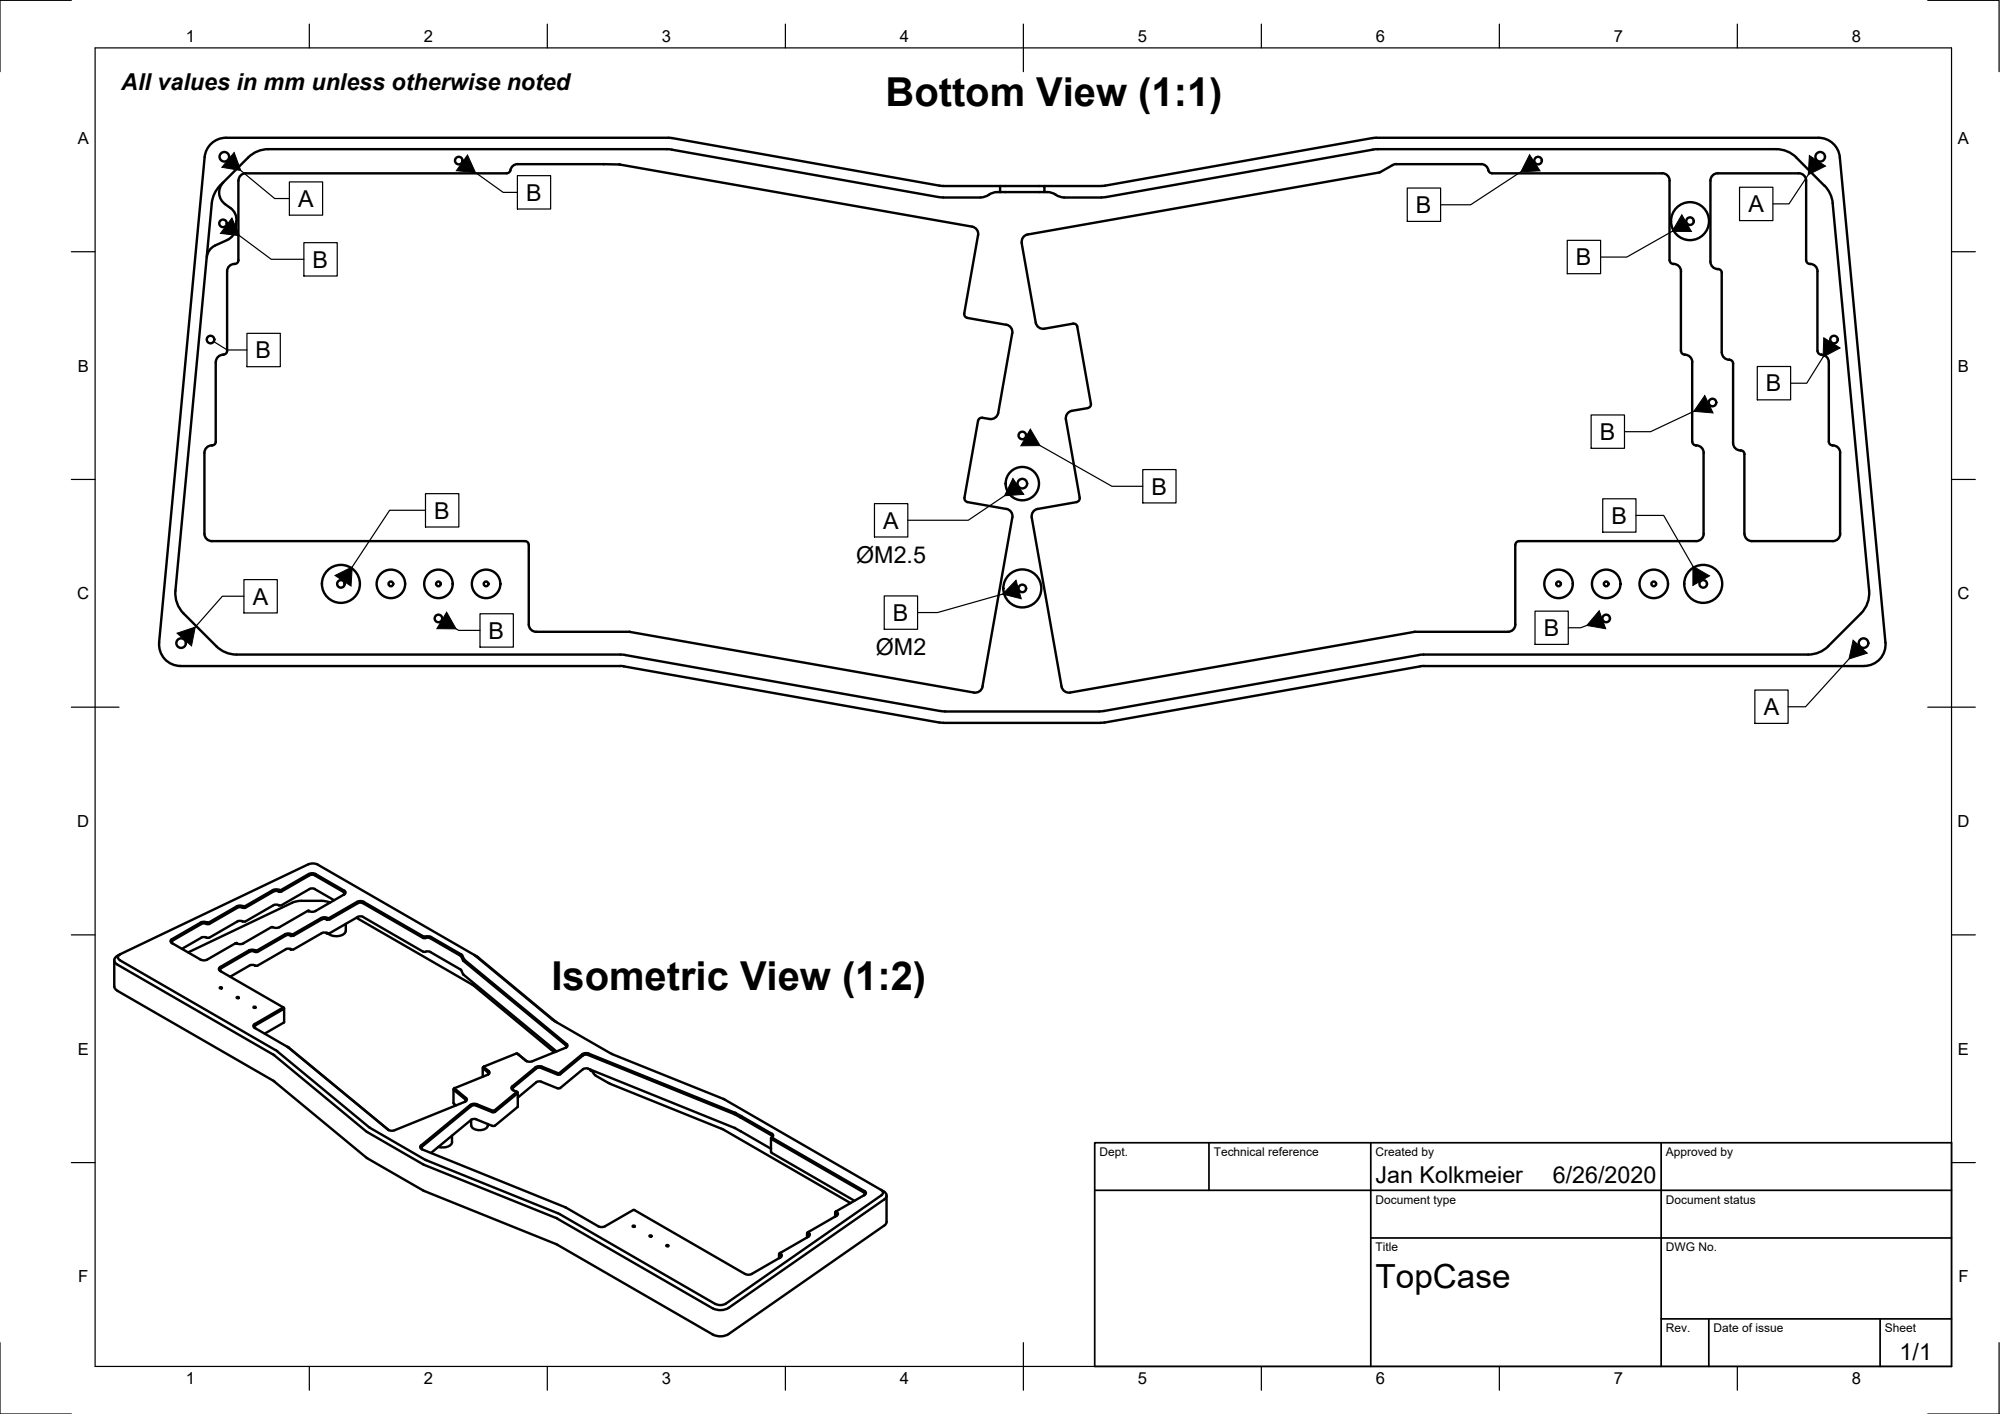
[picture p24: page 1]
Isometric View (1:2)

Bottom View (1:1) All values in mm unless otherwise noted

Dept. | Technical reference | Created by Jan Kolkmeier 6/26/2020 | Approved by

Document type | Document status

Title TopCase | DWG No.

Rev. | Date of issue | Sheet 1/1

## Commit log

2019-10-20 update with PCBv2 :
    [BOM.csv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]
2019-10-20 added center stem back in
    [copper_bottom.gbr, copper_top.gbr, gerber_job.gbrjob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]
2019-11-10 PCBv2 works
    [BOM.csv, BOM_LED.csv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]
2019-11-10 Case Released
    [CaseBottom.stl]
2020-05-17 Case design with separate plate
2020-05-23 Updated Design
    [BOM_LED.csv, BOMv2_1.csv, ExportBottomCase.step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]
2020-05-23 Fix diode position
    [CPLv2_1.csv]
2020-05-23 Fixed default orientation of exported parts
    [ExportBottomCase.step, ExportBottomCase.stl, ExportBottomWeight.step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]
2020-05-24 Was missing holes from pcb profile
2020-05-28 Updated Case with Layout options (2u backspace and 2.25 spacebars)
    [ExportBlocker.step, ExportBottomCase.step, ExportBottomWeight.step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]
2020-06-07 Small tweaks anticipating machining tolerances
    [ExportBlocker.step, ExportBottomCase.step, ExportBottomWeight.step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]
2020-08-09 Update Case Files
    [ExportBlocker.step, ExportBlocker_EngravedLogo.step, ExportBottomCase.step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]
2020-08-09 Rename Files
    [Blocker.step, Blocker_EngravedLogo.step, BottomCase.step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]
2020-08-09 Move Files 2
    [Blocker.step, Blocker_EngravedLogo.step, BottomCase.step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]
2020-08-09 Kicad Files and PCBv3 beta
    [BMEK_Hotswap-B_Mask.gbr, BMEK_Hotswap-B_SilkS.gbr, BMEK_Hotswap-Edge_Cuts.gbr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]
2020-08-10 small fixes, export without hatch-pattern
    [BMEK_Hotswap-B_Mask.gbr, BMEK_Hotswap-B_SilkS.gbr, BMEK_Hotswap-Edge_Cuts.gbr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]
2020-08-10 update gerbers
    [BMEK_Solder-B_Mask.gbr, BMEK_Solder-B_SilkS.gbr, BMEK_Solder-Edge_Cuts.gbr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]
2020-08-10 Crosshatch / normal version
    [BMEK_Hotswap-B_Mask.gbr, BMEK_Hotswap-B_SilkS.gbr, BMEK_Hotswap-Back.gbr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]
2020-08-10 dxf files for plates
    [SwitchPlate.dxf, SwitchPlate_ThreeQuarterFlex.dxf]
2020-08-11 add stls
    [Blocker.stl, BottomCase.stl, TopCase.stl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]
2020-08-15 fix logo
    [BMEK_Hotswap-B_Mask.gbr, BMEK_Hotswap-B_SilkS.gbr, BMEK_Hotswap-Edge_Cuts.gbr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]
2020-09-05 Added jlcpcb ordering steps to pcb README.md
2021-01-31 GB version of all 3D Files Plus source design
    [Blocker.step, Blocker_EngravedLogo.step, BottomCase.step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]
2021-01-31 Final Gerbers used for GB
2021-01-31 Update Kicad Projects, added project for LED stencil
    [BMEK_Hotswap.kicad_sch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]
2021-01-31 Project Files
    [BMEK_Hotswap-B_Mask.gbr, BMEK_Hotswap-B_SilkS.gbr, BMEK_Hotswap-Edge_Cuts.gbr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]
2021-01-31 Kicad Files
    [BMEK_Hotswap.kicad_sch]
2022-05-12 add lasercut case file
    [bottom and feet.dxf, plate.dxf, top case bmek.dxf]
2022-05-12 update readme case\lasercut
2022-05-12 update location
    [bottom and feet.dxf, plate.dxf, top case bmek.dxf]
